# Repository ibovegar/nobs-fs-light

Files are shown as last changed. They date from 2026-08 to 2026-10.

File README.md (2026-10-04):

# Nobs FS Light

A build-it-yourself control panel for flight simulators: **6 rotary encoders** and **2 toggle
switches**, wired to an **Arduino Nano ESP32**. It plugs in over USB and shows up as a standard
game controller (HID gamepad) named **"Nobs FS Light"**, recognised directly by MSFS and the Nobs
app with no drivers to install.

Same physical layout as [Nobs Panel](https://github.com/ibovegar/nobs-fs-panel) (an 8-position
front panel), but 6 of the 8 toggle-switch positions are rotary encoders instead: each has a
push button and reports CW/CCW rotation as momentary presses, for **22 buttons** total (6 × 3 for
the encoders + 2 × 2 for the three-position switches).

## Design Philosophy

**This panel pairs precise, continuous controls with tactile, no-fuss toggles**: rotary encoders
for values you dial in (headings, altitudes, frequencies, anything you'd otherwise nudge one
degree/unit at a time), plain mechanical toggles for the handful of binary states that don't need
a knob. Both are things you can operate by feel alone, no looking needed, which keeps this
VR-friendly, and because it enumerates as a plain USB game controller, there's nothing to install
and nothing that can fall out of sync with a sim update:

* **Encoders for dialing, not clicking:** turning a knob to set a value is more natural (and more
  precise, with acceleration for fast spins) than repeatedly pressing a button.
* **Physical Switches, Not Software:** the 2 toggle switches are genuine switches with a positive
  snap, so flipping one is unambiguous even without looking.
* **Driver-Free by Design:** the board presents itself as a standard HID gamepad, so MSFS and the
  Nobs app recognise it the moment it's plugged in.

> 📸 This module is a fresh design: the enclosure, mounting plate, and front panel are modeled
> ([models/](models/)), but it hasn't been physically built yet, so there are no product photos
> here. See [docs/build-instructions.md](docs/build-instructions.md).

## Docs

- **[Build instructions](docs/build-instructions.md)**: step-by-step assembly (no photos yet, see
  above).
- **[Which wire goes where](docs/arduino-esp-32-wiring.md)**: the button + pin map.
- **[Loading the firmware](firmware/arduino_eps32_nano/README.md)**: first-time flashing,
  re-flashing, and the encoder acceleration protocol, step by step.
- **[Setting the device ID & name](docs/board-identity.md)**: how the board names itself, how to
  rename it, and how to run several panels at once (each gets its own ID + name).
- **[Bill of materials](docs/bill-of-materials.md)**: parts list.

## Nobs FS Companion App

The [**Nobs FS app**](https://github.com/ibovegar/nobs-fs-app) is the companion application for
communicating with and configuring the Nobs family of panels, including this one. It automatically
detects Nobs devices by their USB identity (VID `303A`, per-product PID block), so the right
device is selected even when other game controllers are connected.

Use it to:
* **Verify wiring & test inputs:** watch every encoder and switch register live as you turn or
  flip it, handy for confirming the build before binding anything in the sim.
* **Tune encoder feel:** adjust each encoder's acceleration sensitivity from the Settings page.
* **Track multiple panels:** the Devices page lets you add extra instances of the panel, each with
  its own ID and name (see [Setting the device ID & name](#setting-the-device-id--name-in-brief)
  below), so the app and the sim can tell them apart.

See the app repository for installation and usage details: <https://github.com/ibovegar/nobs-fs-app>

## Setting the device ID & name (in brief)

The board's name and USB product ID aren't compiled in; they're stored on the board, so the same
firmware can be set up as any Nobs profile. Out of the box this is **"Nobs FS Light"** (`303A` /
`80FC`). To change it, the configuration app sends a single line over the board's serial port:

```
SET_ID:80FC:Nobs FS Light
```

The board saves the new name + ID, replies `OK:80FC:Nobs FS Light`, and reboots so it takes effect
(`GET_ID` reads back the current values). For multiple panels, give each one the next ID in the
block, e.g. `SET_ID:80FD:Nobs FS Light 2`. Full details, including the Windows name-cache refresh,
are in **[docs/board-identity.md](docs/board-identity.md)**.

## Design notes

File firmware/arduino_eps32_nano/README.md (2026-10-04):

# Nobs FS Light: Arduino Nano ESP32 Firmware

This is the program (the "firmware") that runs on an **Arduino Nano ESP32** and turns it into a
USB game controller for Microsoft Flight Simulator. Once loaded, the board shows up to your PC and
the Nobs app as **"Nobs FS Light"** with **22 buttons**: 6 rotary encoders (CW, CCW, and push each)
and 2 three-position toggle switches. Wiring is in
[`docs/arduino-esp-32-wiring.md`](../../docs/arduino-esp-32-wiring.md).

> 👍 Everything you need is in this folder. You don't edit any Arduino files. Keep
> [`build_opt.h`](./build_opt.h) next to the sketch: the IDE uses it automatically, and the build
> fails on purpose without it. Tested with the Arduino ESP32 board package `2.0.18-arduino.5`.

## One-time setup

1. Install the **Arduino IDE** (free, from arduino.cc).
2. Add the board: **Tools → Board → Boards Manager…**, search **Arduino ESP32 Boards**, click
   **Install** (big download). Then pick **Tools → Board → Arduino ESP32 Boards → Arduino Nano ESP32**.
3. In **Tools**, set **USB Mode → `Normal mode (TinyUSB)`** and **Pin Numbering → `By Arduino pin (default)`**.

> If the board install fails ("platform not installed"), close the IDE, reopen it **as
> administrator**, and try again.

## Flashing the first time

1. Open [`arduino_eps32_nano.ino`](./arduino_eps32_nano.ino) in the Arduino IDE.
2. Plug in the board with a **data** USB cable (not charge-only), straight into the PC.
3. Click **Upload** (the round arrow).

On a fresh board this just works. 🎉 When it's done, the board reconnects as **"Nobs FS Light"**
and the app picks it up automatically.

## Re-flashing (after firmware is already on it)

This is **different**, and expected. Once the firmware is running, the board reports a custom USB
ID and no longer auto-enters upload mode, so a normal Upload fails with:

```
No DFU capable USB device available — exit status 74
```

Put the board into **update mode** by hand first:

1. Press the **RESET** button **twice, quickly** (like a mouse double-click, ~0.3–0.5 s apart).
2. You're in update mode when the **green LED breathes slowly in and out and stays there**.
   A quick red→blue→green flash that stops is just a normal reset; try the double-tap again.
3. With the green breathing, click **Upload** right away.
4. When it finishes, press **RESET once** to start the firmware.

> **If upload still can't find the board:** it's almost always the **cable or USB port**. Swap to
> a known-good data cable and a different port (this is the most common cause). The double-tap
> timing is the other one; keep trying the rhythm.

## Check it works

- **Nobs app:** the panel is detected automatically; turn the encoders and flip the switches to
  watch them react.
- **Windows:** press `Win`, type **Set up USB game controllers**, open the device's **Properties**,
  and turn/press the controls to see the 22 buttons react.

## Changing the board's name / ID

The name and product ID aren't compiled in; they're stored on the board, so the same firmware can
become any Nobs profile. Out of the box it's **"Nobs FS Light"** (`303A` / `80FC`). The
configuration app changes it over the board's serial port. See
[`docs/board-identity.md`](../../docs/board-identity.md) for how that works and the full profile
list.

## Encoder acceleration sensitivity

Each encoder's rotational acceleration (how much a fast spin multiplies presses-per-detent, vs. a
slow deliberate turn staying 1:1) is host-configurable and persisted to flash. Over the same USB
CDC serial port:

```
A0100\n   # set encoder 0 (ENC1) sensitivity to 100 (0..255)
A0?\n     # query encoder 0's current sensitivity
```

The board replies `A0=100\n` either way. Encoder indices are `0`–`5` for ENC1–ENC6. See the
comment above `applyAccelCommand()` in the sketch for the full protocol, and the comment above
`DETENT_STEPS` for how the acceleration curve itself works.

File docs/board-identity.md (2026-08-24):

# How the Board Names Itself (and How to Rename It)

This page explains, in plain language, how a Nobs board tells your PC who it is, and how you can
change that without re-installing the firmware. You don't need to understand any of this to use
the panel; it's here for the curious and for anyone setting up more than one box.

## The short version

- Every Nobs box appears to your PC as a USB game controller with a **name** (like "Nobs FS Light")
  and an **ID number** (called a *Product ID*, or **PID**).
- That name and ID are **not baked into the firmware**. The board remembers them in its own
  memory, so the *same* firmware can be set up as a panel, an autopilot, an approach box, or this
  light module.
- Out of the box, this board is **"Nobs FS Light"**. You can change it later with the configuration
  app, no re-flashing needed.

## Why each box needs its own name and ID

If you own more than one Nobs box, this matters. Microsoft Flight Simulator keeps a separate set
of button bindings for each controller, but it tells controllers apart by their **ID number**.

If two boxes shared the same ID, the simulator would treat them as the same device and **mix up
their button assignments**. Giving each box its own ID (and a clear name) keeps their controls
neatly separated, so plugging in a second or third box never disturbs the first.

Here are the standard profiles. Each product owns a small **block of IDs** so you can have several
of the same type (see below):

| If the box is a… | It should be named… | ID block |
| :--- | :--- | :--- |
| Panel | Nobs Panel | `80F0`–`80F3` |
| Autopilot | Nobs Autopilot | `80F4`–`80F7` |
| Approach | Nobs Approach | `80F8`–`80FB` |
| Light | Nobs FS Light | `80FC`–`80FF` |

(They all share the same *vendor* ID, `303A`; that part never changes.)

## Running several of the same type

You can use more than one of the same module (say two of these light panels) at the same time.
The catch is they must **not** look identical to the PC, or the simulator mixes up their bindings.
So each one gets its own ID and name from its product's block:

| | Name | ID |
| :-- | :-- | :-- |
| 1st light panel | Nobs FS Light | `80FC` |
| 2nd light panel | Nobs FS Light 2 | `80FD` |
| 3rd light panel | Nobs FS Light 3 | `80FE` |

The first one keeps the plain name and the block's first ID (its out-of-box default). For each
extra one, give it the next ID and a numbered name with the rename step below, e.g. send
`SET_ID:80FD:Nobs FS Light 2` to the second one. In the Nobs app, open **Devices** and press **+**
on that product to start tracking the extra module. The simulator then sees "Nobs FS Light" and
"Nobs FS Light 2" as two separate controllers with independent bindings.

## How to rename a board

The configuration app does this for you. Behind the scenes it just sends the board one short line
of text over its connection, for example:

```
SET_ID:80FC:Nobs FS Light
```

That reads as: *"Set your ID to `80FC` and your name to `Nobs FS Light`."* The board then:

1. **Saves** the new name and ID into its own memory.
2. **Confirms** it received them.
3. **Restarts itself** and comes back wearing the new name.

That restart is normal and only takes a second. The reason it's needed: a board can only announce
its identity to the PC at the moment it powers on, so it has to reboot for a new name to take
effect.

> 💡 To check what a board is currently called, the app can ask it with `GET_ID`, and the board
> replies with its stored name and ID.

## If Windows still shows the old name

Windows likes to remember names, so occasionally after a rename it'll keep showing the **old** one
in its game-controller list or in the simulator. If that happens, nudge it to take a fresh look:

1. Leave the board plugged in.
2. Right-click the **Start** button → open **Device Manager**.
3. Open the **Human Interface Devices** group.
4. Right-click your controller → **Uninstall device**.
5. Unplug the USB cable, wait a couple of seconds, and plug it back in.

Windows will then read the board's name again from scratch and show the updated one.

## Related pages

- [Which wire goes where](./arduino-esp-32-wiring.md): the button and pin map.
- [Loading the firmware](../firmware/arduino_eps32_nano/README.md): step-by-step setup, including
  the more technical details of how the identity is stored, and the encoder acceleration protocol.

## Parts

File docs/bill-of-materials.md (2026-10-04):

# Bill of Materials (Shopping List)

This is the full shopping list for building one Nobs FS Light: every part you need, from the
electronics to the screws. The "Manufacturer / Part Number" column lists parts known to work,
linked to their Mouser listing, so you can search for them or find equivalents.

A few friendly notes before you start buying:

- **Exact parts aren't mandatory.** The encoders, switches, terminal blocks, and stripboard can be
  swapped for similar parts you like or already have. The part numbers here are just what's known
  to work.
- **The enclosure parts (section 2) are 3D printed**: the top/bottom shells are shared with the
  rest of the Nobs family, and the mounting plate and front plate are modeled for this module's
  6-encoder / 2-switch layout. Print them yourself from the files in the `models/` folder, or have
  a print service make them.
- Quantities are for **one** panel.

## Core Electronics & Switches

| Item # | Qty | Component Description | Manufacturer / Part Number | Purpose / Application |
| :--- | :--- | :--- | :--- | :--- |
| **1.1** | 1 | Arduino Nano ESP32 (with headers) | [Arduino / ABX00083](https://no.mouser.com/ProductDetail/Arduino/ABX00083) | Main microcontroller (ESP32-S3, USB HID, VID 0x303A / PID 0x80FC) |
| **1.2** | 6 | Rotary Encoder, 12 mm, with Momentary Push Switch, 24 detents | [Bourns / PEC11R-4215F-S0024](https://www.mouser.com/ProductDetail/Bourns/PEC11R-4215F-S0024) | ENC1–ENC6 |
| **1.3** | 2 | SPDT Toggle Switch, ON-OFF-ON (3-position) | *Part number to be chosen* | SW1–SW2 |
| **1.4** | 1 | Stripboard, 50 × 80 mm | [BusBoard Prototype Systems / ST1](https://no.mouser.com/ProductDetail/BusBoard-Prototype-Systems/ST1) | Controller board carrier for the Arduino, pin headers, and terminal blocks |
| **1.5** | 2 | Female Pin Header Socket, 26-position, 2.54 mm pitch | [3M Electronic Solutions Division / 929850-01-26-RA](https://no.mouser.com/ProductDetail/3M-Electronic-Solutions-Division/929850-01-26-RA) | Sockets soldered to the stripboard to seat the Arduino Nano ESP32 |
| **1.6** | 4 | Fixed Terminal Block, 6-position, 2.54 mm pitch | [GCT / TBC05-06-1-G-G](https://no.mouser.com/ProductDetail/GCT/TBC05-06-1-G-G) | Screw-down wiring for the 22 encoder/switch signal wires and ground |
| **1.7** | 1 | 3 mm Green LED, Diffused, 2.2 V | [Lumex / SSL-LX30FT4GD](https://no.mouser.com/ProductDetail/Lumex/SSL-LX30FT4GD?qs=7jmq9uQgtYG4HR2h%252BlgbMw%3D%3D) | Front-plate status indicator |
| **1.8** | 1 | 120 Ω Resistor, 1/4 W, ±1%, Metal Film | [KOA Speer / MFS1/4DCT52R1200F](https://no.mouser.com/ProductDetail/KOA-Speer/MFS1-4DCT52R1200F?qs=ddCg%252BR5cWn20oJHZLuYO%2FQ%3D%3D) | Current-limiting resistor for the status LED |
| **1.9** | 6 | Knurled Encoder Knob, 6 mm D-shaft | Generic aftermarket | Grip/cap for ENC1–ENC6 |
| **1.10** | 2 | Toggle Switch Cap, Bat Lever, White | [NKK Switches / AT434B](https://no.mouser.com/ProductDetail/NKK-Switches/AT434B?qs=O05gvr8fLT2J5h7R71L7Aw%3D%3D) | Color-coded cap for toggle switches |

## Structural & Enclosure Hardware

| Item # | Qty | Component Description | Manufacturer / Part Number | Purpose / Application |
| :--- | :--- | :--- | :--- | :--- |
| **2.1** | 1 | Enclosure Top | 3D Printed (`models/enclosure_top.stl`) | Main upper housing shell |
| **2.2** | 1 | Enclosure Bottom | 3D Printed (`models/enclosure_bottom.stl`) | Main lower housing base, carries the controller board |
| **2.3** | 1 | Mounting Plate | 3D Printed (`models/nobs_light_mounting_plate.stl`) | Carries the 6 encoders and 2 toggle switches |
| **2.4** | 1 | Front Plate | 3D Printed (`models/nobs_light_frontpanel.stl`) | Visual faceplate with control labels |
| **2.5** | 10 | M4 Heat-Set Insert | [SI (PennEngineering) / IUTB-M4](https://no.mouser.com/ProductDetail/SI/IUTB-M4) | Threaded anchors moulded into the enclosure top/bottom |
| **2.6** | 11 | M3 Heat-Set Insert | [SI (PennEngineering) / IUTB-M3](https://no.mouser.com/ProductDetail/SI/IUTB-M3) | Threaded anchors moulded into the mounting plate and front plate |
| **2.7** | 4 | M4 × 0.7, 30 mm Socket-Head Screw | — | Clamps the enclosure top and bottom halves together |
| **2.8** | 6 | M4 × 0.7, 10 mm Socket-Head Screw | — | Fastens the mounting plate to the rear of the enclosure bottom |
| **2.9** | 4 | M3 × 0.5, 8 mm Pan-Head Screw | — | Fastens the controller board to its standoffs in the enclosure bottom |
| **2.10** | 7 | M3 × 0.5, 8 mm Countersunk Screw | — | Fastens the front plate to the mounting plate, and the assembly to the enclosure |

> ⚠️ Section 2 quantities are carried over from the other Nobs modules as a starting estimate; treat
> them as a first pass until a build confirms exact fastener counts for this module's parts.

## Connectors & Wiring

| Item # | Qty | Component Description | Manufacturer / Part Number | Purpose / Application |
| :--- | :--- | :--- | :--- | :--- |
| **3.1** | 1 | USB-C to USB-A Cable, 1.5 m to 2 m, data-sync capable | — | Connects the Arduino Nano ESP32 to your PC |
| **3.2** | 1 | Heat Shrink Tubing Assortment Pack, 1.5 mm to 3.5 mm diameters | — | Insulates soldered connections on the encoder and switch terminals |

## Tools Recommended for Assembly (Not in BOM Cost)

* **Soldering Iron & Lead-Free Rosin-Core Solder:** for attaching wires to the encoder/switch
  terminals and seating the pin headers/terminal blocks on the stripboard.
* **Wire Strippers & Flush Cutters:** for prepping the signal and ground wires.
* **Soldering Iron / Insert Tool for Heat-Set Inserts:** for pressing the brass inserts squarely
  into the 3D-printed parts.
* **Multimeter:** for testing continuity and checking for short circuits across the common ground
  loop before plugging into USB power.

## Project Costs

Rough cost estimate for a single panel, in USD. These are ballpark figures only, actual prices
vary significantly by supplier, region, and quantity, and **exclude shipping and taxes**. Several
items (heat-set inserts, screws) are sold in multi-build packs, so the per-build cost is lower if
you build more than one or already have them on hand.

| Category | Items | Estimated Cost |
| :--- | :--- | ---: |
| Microcontroller | Arduino Nano ESP32 (genuine; clones are cheaper) | $20 – $28 |
| Encoders & switches | 6 × Bourns PEC11R-4215F-S0024 + 2 × 3-position toggle switches | $30 – $50 |
| Board & connectors | Stripboard, 2 × pin headers, 4 × terminal blocks, status LED | $12 – $18 |
| Fasteners | Heat-set inserts (21) and M3/M4 screws (21) | $10 – $18 |
| Enclosure (3D printed) | Filament for top, bottom, mounting plate, front plate | $5 – $15 |
| Connectors & wiring | USB-C cable, heat-shrink tubing pack, encoder knobs | $10 – $20 |
| **Total** | | **≈ $87 – $149** |

> **Notes:**
> * The **enclosure** assumes you print the parts yourself (filament cost only). Ordering them
>   from a print service will add roughly $20 – $50.
> * This estimate doesn't include hookup wire, since it's usually bought once in bulk and reused
>   across builds.
> * Bulk/pack purchasing of the inserts, screws, and heat-shrink tubing spreads their cost across
>   multiple builds, lowering the effective per-panel total.

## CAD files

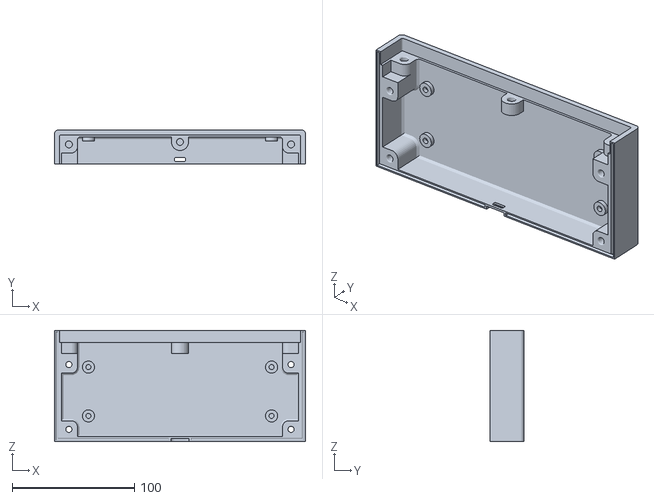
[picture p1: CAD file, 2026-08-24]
models/enclosure_top.stl
205.6 x 27.8 x 91.0

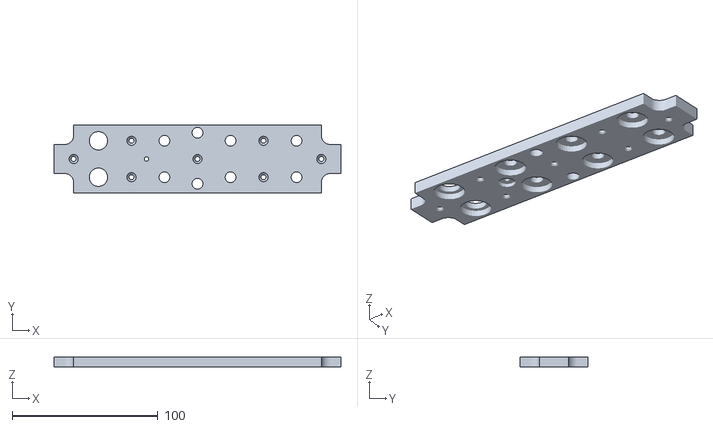
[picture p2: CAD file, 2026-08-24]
models/nobs_light_frontpanel.stl
197.0 x 47.0 x 7.00

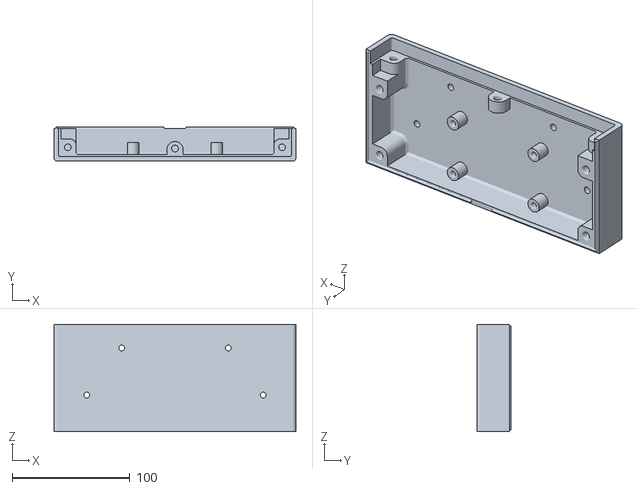
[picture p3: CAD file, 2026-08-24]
models/enclosure_bottom.stl
205.6 x 29.3 x 91.0

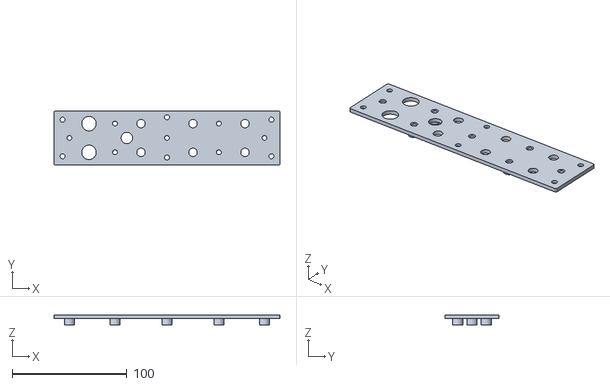
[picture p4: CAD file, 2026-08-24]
models/nobs_light_mounting_plate.stl
197.0 x 47.0 x 9.00

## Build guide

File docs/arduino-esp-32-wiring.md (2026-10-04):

# Wiring Map: Which Wire Goes Where

This table tells you which pin on the board each wire connects to, for the **Arduino Nano ESP32**.

This box has **6 rotary encoders** (ENC1–ENC6, each with an integrated push button) and **2 toggle
switches** (SW1–SW2, 3-position ON-OFF-ON). Every encoder has three signal terminals (Phase A,
Phase B, and its push-button switch terminal) plus a common terminal; every toggle switch has two
signal terminals (1 and 3) plus a common terminal (2). All the common terminals go to **GND**.

**How to read a row:** find the control (e.g. "ENC1"), look at which terminal it is ("Phase A
Terminal"), then run a wire from that terminal to the pin listed in the board's column. Pin names
like `D13` or `A0` are printed on the board itself. Every control's common terminal connects to
**GND** (ground), see the last row.

The "Virtual HID Button" column is just for reference: it's the button number the sim sees when you
turn, push, or flip that control. You don't wire anything for it.

> 💡 Each terminal has one wire to its signal pin (from this table) and the common terminal wires
> to **GND**. No resistors or extra parts needed; the firmware handles that.

| Component Group | Component Label | Hardware Connection | Arduino Nano ESP32 Pin | Virtual HID Button | Action Type |
| :--- | :--- | :--- | :--- | :--- | :--- |
| **ENC1** | Encoder 1 | Phase A Terminal | **D12** | Button 1 | CW Pulse |
| | Encoder 1 | Phase B Terminal | **D11** | Button 2 | CCW Pulse |
| | Encoder 1 | Switch Terminal | **D10** | Button 3 | Push |
| **ENC2** | Encoder 2 | Phase A Terminal | **D9** | Button 4 | CW Pulse |
| | Encoder 2 | Phase B Terminal | **D8** | Button 5 | CCW Pulse |
| | Encoder 2 | Switch Terminal | **D7** | Button 6 | Push |
| **ENC3** | Encoder 3 | Phase A Terminal | **D6** | Button 7 | CW Pulse |
| | Encoder 3 | Phase B Terminal | **D5** | Button 8 | CCW Pulse |
| | Encoder 3 | Switch Terminal | **D4** | Button 9 | Push |
| **ENC4** | Encoder 4 | Phase A Terminal | **D3** | Button 10 | CW Pulse |
| | Encoder 4 | Phase B Terminal | **D2** | Button 11 | CCW Pulse |
| | Encoder 4 | Switch Terminal | **D0** | Button 12 | Push |
| **ENC5** | Encoder 5 | Phase A Terminal | **D13** | Button 13 | CW Pulse |
| | Encoder 5 | Phase B Terminal | **D17 (A0)** | Button 14 | CCW Pulse |
| | Encoder 5 | Switch Terminal | **D18 (A1)** | Button 15 | Push |
| **ENC6** | Encoder 6 | Phase A Terminal | **D19 (A2)** | Button 16 | CW Pulse |
| | Encoder 6 | Phase B Terminal | **D20 (A3)** | Button 17 | CCW Pulse |
| | Encoder 6 | Switch Terminal | **D21 (A4)** | Button 18 | Push |
| **Switches** | Switch 1 (SW1) | Terminal 1 | **D24 (A7)** | Button 21 | Toggle (position 1) |
| | Switch 1 (SW1) | Terminal 3 | **D1** | Button 22 | Toggle (position 3) |
| | Switch 2 (SW2) | Terminal 1 | **D22 (A5)** | Button 19 | Toggle (position 1) |
| | Switch 2 (SW2) | Terminal 3 | **D23 (A6)** | Button 20 | Toggle (position 3) |
| **Ground Loop** | All Components | Common / GND Terminals (incl. SW terminal 2) | **GND** | *None* | System Ground |
| **Status LED** | Status LED | Anode, via 120 Ω resistor | **B0** | *None* | Boot/Connect Status |
| | Status LED | Cathode | **GND** | *None* | Boot/Connect Status |

> 💡 **Status LED:** wired with a 120 Ω current-limiting resistor from **B0** to **GND**. It blinks
> while the board is booting/waiting for USB enumeration and lights steady once the host PC has
> enumerated it. If no host shows up within 10 seconds it goes dark. B0 also drives the red
> channel of the board's own RGB LED (inverted), so that one glows red whenever the status LED is
> off. Leave **B1** (next to it) unconnected: it selects the chip's boot mode, and pulling it to
> ground stops the board from starting.

> 💡 **Three-position switches:** SW1 and SW2 are ON-OFF-ON toggles. Terminal 2 (centre) goes to
> **GND**; flipping to one side connects terminal 2 to terminal 1, the other side to terminal 3,
> and the centre position connects neither (both buttons released).

> 💡 **D17–D24 are the same pins as A0–A7.** Both labels are printed on the board.

> 💡 **D0/D1 as plain GPIO:** these pins double as the hardware UART (Serial) on most Arduino
> boards, but this firmware disables "USB CDC On Boot" (see
> [`firmware/arduino_eps32_nano/build_opt.h`](../firmware/arduino_eps32_nano/build_opt.h)) and never
> calls `Serial.begin()`, so they're free for plain digital input.

> 💡 **D13 is the built-in LED pin.** On the Nano ESP32, D13 doubles as the built-in amber LED
> (`LED_BUILTIN` / GPIO48), so that LED stays lit while the firmware runs. Every `D` and `A` pin on
> the board is used, which is why the status LED sits on **B0**.

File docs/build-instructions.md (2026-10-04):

# Build Instructions

> 📸 This module hasn't been physically built yet, so unlike the other Nobs repos this guide has
> no step photos. The sequence below follows the same two-stage process (controller board, then
> enclosure) as [Nobs Panel](https://github.com/ibovegar/nobs-fs-panel/blob/main/docs/build-instructions.md)
> and [Nobs Autopilot](https://github.com/ibovegar/nobs-fs-autopilot/blob/main/docs/build-instructions.md).
> Photos will be added here once a first unit is assembled.

Before starting, gather everything on the [bill of materials](bill-of-materials.md) and have the
[wiring map](arduino-esp-32-wiring.md) open for reference.

## 1. Controller board

1. Solder the two 26-position female pin header sockets to the stripboard, spaced to match the
   Arduino Nano ESP32's own header pitch, then seat the Arduino into them.
2. Solder the 4 six-position terminal blocks to the stripboard, giving you screw terminals for the
   22 signal wires (6 encoders × 3 terminals + 2 switches × 2 terminals) plus a shared ground rail.
3. Wire the 120 Ω resistor in series with the status LED's anode, and run the LED's anode/cathode
   to **B0** / **GND** as described in the wiring map. Leave **B1** (next to it) unconnected: tying
   it to ground stops the board from starting.
4. Double-check every connection against [arduino-esp-32-wiring.md](arduino-esp-32-wiring.md)
   before applying USB power. A multimeter continuity check across the ground loop catches most
   wiring mistakes early.

## 2. Encoders and switches

1. Print the mounting plate ([`models/nobs_light_mounting_plate.stl`](../models/nobs_light_mounting_plate.stl))
   and mount the 6 rotary encoders and 2 toggle switches to it.
2. Each encoder has 5 terminals: Phase A, Phase B, the push-switch's two terminals (bridge them or
   wire one to signal and the other to the shared ground rail, per the encoder's datasheet), and
   the encoder body/shaft ground tab if present. Wire Phase A, Phase B, and the push switch's
   signal terminal to their pins per the wiring map; wire every remaining common terminal to GND.
3. Each toggle switch is a 3-position ON-OFF-ON type with 3 terminals: wire terminals 1 and 3 to
   their signal pins and the centre terminal (2) to GND.
4. Insulate each soldered joint with heat-shrink tubing.
5. Press the knurled knob caps onto the encoder shafts and the bat-lever caps onto the toggle
   switches.

## 3. Firmware

Flash the sketch in [`firmware/arduino_eps32_nano/`](../firmware/arduino_eps32_nano/) following
that folder's [README](../firmware/arduino_eps32_nano/README.md). Do this before final enclosure
assembly so you can test every control (encoder rotation, encoder push, both switches) while
everything is still accessible.

## 4. Enclosure

1. Press the M4 and M3 heat-set inserts into the enclosure top/bottom, mounting plate, and front
   plate with a soldering iron or dedicated insert tool.
2. Fasten the controller board to its standoffs in the enclosure bottom with the M3 pan-head
   screws.
3. Fasten the mounting plate (with encoders and switches already installed) to the rear of the
   enclosure bottom with the M4 × 10 mm screws.
4. Fasten the front plate to the mounting plate assembly with the M3 countersunk screws.
5. Route the USB-C cable out through the enclosure's cutout, then close the top and bottom halves
   with the M4 × 30 mm screws.

## 5. Check it works

Follow [Check it works](../firmware/arduino_eps32_nano/README.md#check-it-works) in the firmware
README: confirm all 6 encoders register CW/CCW/push and both switches register on/off, either in
the Nobs app or Windows' **Set up USB game controllers** panel.

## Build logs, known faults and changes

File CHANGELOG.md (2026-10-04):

# Changelog

All notable changes to the Nobs FS Light project (hardware, firmware, and documentation) are documented in this file.

The format is based on [Keep a Changelog](https://keepachangelog.com/en/1.1.0/),
and this project adheres to [Semantic Versioning](https://semver.org/spec/v2.0.0.html).

## [Unreleased]

### Added
- Project scaffold, modeled on [nobs-fs-panel](https://github.com/ibovegar/nobs-fs-panel): same
  folder layout, `.gitignore`, and AGPLv3 license.
- Wiring map ([docs/arduino-esp-32-wiring.md](docs/arduino-esp-32-wiring.md)): 6 encoders (18
  pins) + 2 three-position toggle switches (4 pins) fill every D/A pin on the Arduino Nano ESP32,
  with the status LED on B0.
- Bill of Materials ([docs/bill-of-materials.md](docs/bill-of-materials.md)): core electronics,
  encoders, switches, structural/enclosure hardware (pending final mounting-plate design), and a
  per-panel project cost estimate.
- Build instructions ([docs/build-instructions.md](docs/build-instructions.md)): textual walkthrough
  covering controller board, encoders/switches, firmware, and enclosure; no step photos yet since
  the module hasn't been physically built.
- Board identity guide ([docs/board-identity.md](docs/board-identity.md)), reserving PID block
  `80FC`–`80FF` / "Nobs FS Light" in the shared Nobs USB ID scheme (after Panel `80F0`–`80F3`,
  Autopilot `80F4`–`80F7`, Approach `80F8`–`80FB`).
- Arduino Nano ESP32 firmware sketch
  ([firmware/arduino_eps32_nano/arduino_eps32_nano.ino](firmware/arduino_eps32_nano/arduino_eps32_nano.ino)):
  6-encoder quadrature decoding, per-encoder acceleration, and dynamic USB identity, adapted from
  [nobs-fs-autopilot](https://github.com/ibovegar/nobs-fs-autopilot)'s proven encoder code, plus 2
  three-position (ON-OFF-ON) toggle switches read through both outer terminals, for 22 HID
  buttons. Before starting its own USB the firmware briefly drops the USB pull-up, so the host
  sees the chip's boot-time `303A:1001` device disconnect and enumerates the Nobs device on a
  cold plug-in (without it the board was only detected right after a flash).
- Enclosure, mounting plate, and front panel CAD
  ([models/](models/): shared `enclosure_top`/`enclosure_bottom` shells plus new
  `nobs_light_mounting_plate.stl` and `nobs_light_frontpanel.stl` for the 6-encoder / 2-switch
  layout).
- `images/` placeholder, pending a first physical build.

[Unreleased]: https://github.com/ibovegar/nobs-fs-light/commits/main

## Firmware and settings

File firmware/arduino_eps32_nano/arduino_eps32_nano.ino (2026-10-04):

// Nobs FS Light — Arduino Nano ESP32 (ESP32-S3) USB HID gamepad firmware.
//
// A lighter sibling of the Nobs Autopilot build: same encoder-decoding approach,
// scaled to 6 encoders, with 2 three-position (ON-OFF-ON) toggle switches standing in
// for the other two boxes' larger switch banks. Exposes 22 buttons in the exact order
// the nobs-fs app expects:
//   buttons  0..17  → 6 encoders × (CW, CCW, push)
//   buttons 18..21  → 2 toggle switches × 2 (SW2 pos1, SW2 pos3, SW1 pos1, SW1 pos3)
// See docs/arduino-esp-32-wiring.md for the full button + pin table.
//
// Host config: over the USB CDC serial port the app sets encoder acceleration
// sensitivity and can reassign the board's USB identity — see the serial protocol
// near handleSerialConfig().
//
// ── Arduino IDE Tools settings (required) ─────────────────────────────────────
//   Board:        "Arduino Nano ESP32"
//   USB Mode:     "Normal mode (TinyUSB)"    ← the default; needed for custom HID
//   Pin Numbers:  "By Arduino pin (default)"  so D0/A0… match the wiring doc
// No other Tools changes and NO edits to the installed Arduino core are needed — the
// whole USB-identity fix lives in this repo (this sketch + build_opt.h beside it).
//
// ── USB identity: dynamic, stored in NVS (Preferences) ────────────────────────
// The device enumerates with VID 0x303A (Espressif's vendor ID) and a PID + product
// name that are *configurable at runtime*. Each Nobs box gets its own PID so MSFS
// can't mirror/overwrite control bindings across panels. Out of the box this build
// defaults to PID 0x80FC / "Nobs FS Light" (matches the `light` entry in the app's
// device registry, src/panel/panel.ts).
//
// The PID and name live in flash via the native Preferences library (NVS). On boot
// the firmware reads them *before* USB.begin() and applies them to the descriptor.
// The configuration app can change them over the USB CDC serial port (see the serial
// protocol below); after a change the firmware reboots so USB re-enumerates.
//
// That only works because the Nano ESP32 normally forces "USB CDC On Boot" and "DFU On
// Boot" on, which would make the core bring USB up at boot (before setup()), freezing
// the descriptor with the stock 0x2341/0x0070 identity. The build_opt.h file next to
// this sketch overrides both to 0 (it is appended to every compile, including the
// core's), so the boot-time USB.begin() is skipped and our runtime identity wins.
//
// Because "CDC On Boot" is then off, the core's `Serial` is the hardware UART — so the
// app's config port is our own USB CDC interface (the USBSerial object below). That
// also frees D0/D1 (normally UART0 TX/RX) for plain digital input, which is how SW1
// gets one of its pins below.
//
// Re-flashing: the running firmware reports a custom PID (and, with DFU-on-boot off, no
// DFU runtime interface), so the IDE can't auto-enter the bootloader. Double-tap the
// RESET button (RGB LED pulses) before uploading. See this folder's README.md.

#include "USB.h"
#include "USBHID.h"
#include "USBCDC.h"
#include <EEPROM.h>
#include <Preferences.h>
#include "soc/usb_serial_jtag_reg.h"

#if ARDUINO_USB_MODE
#error "Set Tools > USB Mode to 'Normal mode (TinyUSB)'. Custom HID needs the TinyUSB stack."
#endif
#if ARDUINO_USB_CDC_ON_BOOT
#error "build_opt.h is not taking effect: ARDUINO_USB_CDC_ON_BOOT must be 0. Make sure build_opt.h sits next to this .ino (it disables CDC/DFU-on-boot so the runtime USB identity works)."
#endif

// ── Custom HID gamepad: 22 buttons, no axes ───────────────────────────────────
// 22 1-bit buttons + 2 bits of padding = a flat 3-byte report, driven through the
// ESP32 core's USBHID device interface (same descriptor shape as Nobs Autopilot).
static const uint8_t HID_REPORT_DESCRIPTOR[] = {
  0x05, 0x01,        // Usage Page (Generic Desktop)
  0x09, 0x05,        // Usage (Game Pad)
  0xA1, 0x01,        // Collection (Application)
  0x05, 0x09,        //   Usage Page (Button)
  0x19, 0x01,        //   Usage Minimum (Button 1)
  0x29, 0x16,        //   Usage Maximum (Button 22)
  0x15, 0x00,        //   Logical Minimum (0)
  0x25, 0x01,        //   Logical Maximum (1)
  0x75, 0x01,        //   Report Size (1)
  0x95, 0x16,        //   Report Count (22)
  0x81, 0x02,        //   Input (Data,Var,Abs)
  0x75, 0x01,        //   Report Size (1)
  0x95, 0x02,        //   Report Count (2)   — padding to a whole byte
  0x81, 0x03,        //   Input (Const,Var,Abs)
  0xC0               // End Collection
};

class NobsGamepad : public USBHIDDevice {
public:
  NobsGamepad() { HID.addDevice(this, sizeof(HID_REPORT_DESCRIPTOR)); }

  void begin() { HID.begin(); }

  // Set/clear one button bit in the pending report (mirrors Joystick.setButton).
  void setButton(uint8_t index, uint8_t value) {
    if (index >= 22) return;
    uint8_t byteIdx = index >> 3;
    uint8_t mask    = 1 << (index & 7);
    if (value) report[byteIdx] |= mask;
    else       report[byteIdx] &= ~mask;
  }

  // One USB report carrying every button change since the last call (mirrors
  // Joystick.sendState). Only transmitted when something actually changed — HID
  // hosts track button state edge-to-edge, so re-sending identical reports just
  // adds USB traffic and risks blocking the loop.
  void sendState() {
    if (memcmp(report, lastSent, sizeof(report)) == 0) return;
    if (HID.SendReport(0, report, sizeof(report))) {
      memcpy(lastSent, report, sizeof(report));
    }
  }

  // USBHIDDevice: hand the descriptor to the core during enumeration.
  uint16_t _onGetDescriptor(uint8_t* buffer) override {
    memcpy(buffer, HID_REPORT_DESCRIPTOR, sizeof(HID_REPORT_DESCRIPTOR));
    return sizeof(HID_REPORT_DESCRIPTOR);
  }

private:
  USBHID  HID;
  uint8_t report[3]   = { 0, 0, 0 };
  uint8_t lastSent[3] = { 0xFF, 0xFF, 0xFF }; // force the first real report out
};

NobsGamepad Joystick;

// USB CDC config port. With CDC-on-boot disabled (via build_opt.h) the core's `Serial`
// is the hardware UART, so we expose our own USB CDC interface for the app's Settings
// page. Like USBHID, USBCDC registers its interface in its constructor (static init),
// so it is in place before USB.begin() builds the composite descriptor in setup().
USBCDC USBSerial;

// ── Dynamic USB identity (NVS via Preferences) ────────────────────────────────
// VID is fixed (Espressif's vendor ID); PID + product name are stored in flash and
// host-configurable. Defaults are the light profile; an unconfigured chip uses them.
// (Acceleration uses the emulated-EEPROM store below; identity uses its own
// Preferences namespace, so the two don't collide.)
// NB: named NOBS_USB_VID, not USB_VID — the core's pins_arduino.h #defines USB_VID.
const uint16_t NOBS_USB_VID  = 0x303A;
const uint16_t DEFAULT_PID   = 0x80FC;
const char*    DEFAULT_NAME  = "Nobs FS Light";
const char*    NVS_NAMESPACE = "nobs";
const char*    NVS_KEY_PID   = "pid";
const char*    NVS_KEY_NAME  = "name";

Preferences prefs;
uint16_t     usbPid;  // active PID (kept alive for the whole session)
String       usbName; // active product name (c_str() must outlive USB.begin())

void loadIdentity() {
  prefs.begin(NVS_NAMESPACE, true); // read-only
  usbPid  = prefs.getUShort(NVS_KEY_PID, DEFAULT_PID);
  usbName = prefs.getString(NVS_KEY_NAME, DEFAULT_NAME);
  prefs.end();
}

void storeIdentity(uint16_t pid, const String& name) {
  prefs.begin(NVS_NAMESPACE, false); // read-write
  prefs.putUShort(NVS_KEY_PID, pid);
  prefs.putString(NVS_KEY_NAME, name);
  prefs.end();
}

// ── USB string descriptors: name the interfaces after the product ─────────────
// The core hardcodes the HID/CDC *interface* strings to "TinyUSB HID"/"TinyUSB CDC".
// For a composite device (HID + CDC) Windows and MSFS show that interface string as
// the controller's name — so without this it shows up as "TinyUSB HID" even though
// iProduct is "Nobs FS Light". tud_descriptor_string_cb is weak in the core, so
// defining it here replaces it (no core edit needed) and points every interface
// string at the product name. Index map: 0=language, 1=manufacturer, 2=product,
// 3=serial (from the chip MAC, stable per board), 4+=interface strings → product.
extern "C" const uint16_t* tud_descriptor_string_cb(uint8_t index, uint16_t langid) {
  (void)langid;
  static uint16_t desc[40];

  if (index == 0) {
    desc[1] = 0x0409; // English (United States)
    desc[0] = (uint16_t)((3 << 8) | (2 * 1 + 2));
    return desc;
  }
  // Beyond our real strings (1..3 + a handful of interface strings). Returning NULL
  // mirrors the core and lets Windows' MS-OS probe at index 0xEE fail cleanly.
  if (index >= 16) return NULL;

  char serial[16];
  const char* str;
  switch (index) {
    case 1: str = "Arduino"; break;       // manufacturer (matches USB.manufacturerName)
    case 2: str = usbName.c_str(); break; // product (iProduct)
    case 3:                               // serial — stable per board
      snprintf(serial, sizeof(serial), "%012llX", (unsigned long long)ESP.getEfuseMac());
      str = serial;
      break;
    default: str = usbName.c_str(); break; // HID/CDC/config interface strings
  }

  uint8_t chr_count = strlen(str);
  if (chr_count > 38) chr_count = 38; // desc holds 39 UTF-16 chars + the header word
  for (uint8_t i = 0; i < chr_count; i++) desc[1 + i] = str[i];
  desc[0] = (uint16_t)((3 << 8) | (2 * chr_count + 2));
  return desc;
}

// ── Pin assignments (Arduino Nano ESP32 labels — see arduino-esp-32-wiring.md) ─
// Encoders: A/B quadrature pins + S push button. Encoder common terminals and the
// switches' common terminals are all wired to GND.
//
// Every D/A header pin is used (the status LED sits on B0, see below). A0..A7 are the
// same pins as D17..D24. D13 doubles as
// the built-in amber LED (GPIO48), so that LED stays lit while the firmware runs.
const uint8_t encA[6]    = { D12, D9, D6, D3, D13, A2 };
const uint8_t encB[6]    = { D11, D8, D5, D2, A0,  A3 };
const uint8_t encPush[6] = { D10, D7, D4, D0, A1,  A4 };

// 3-position ON-OFF-ON toggle switches SW1..SW2: terminals 1 and 3 go to the MCU and
// the common (2) to GND. Centre = neither pin LOW. Order: SW2 t1, SW2 t3, SW1 t1, SW1 t3.
const uint8_t swPin[4]   = { A5, A6, A7, D1 };

// NOTE: every pin above is driven with INPUT_PULLUP, so the closed-to-GND wiring
// reads LOW = pressed. All of these GPIOs support the ESP32-S3 internal pull-up;
// if a future revision moves a signal onto a pull-up-less pad, add an external
// 10 kΩ pull-up to 3V3 there.

// ── Status LED (B0) ────────────────────────────────────────────────────────────
// Blinks while booting/waiting for USB enumeration, steady once enumerated. All the
// D/A pins are taken by the controls, so the LED sits on the B0 header pin. B0 is
// GPIO46, which the core names LED_RED: it also drives the red channel of the
// on-board RGB LED, active-low, so that one shows the inverse of the status LED.
// GPIO46 is a boot strapping pin that must read LOW at reset; the LED + resistor to
// GND keeps it there. (Never use B1 instead: that is GPIO0, the boot-mode pin.)
const uint8_t STATUS_LED_PIN = LED_RED;

// ── Button index map (must match the wiring doc / src/panel/panel.ts) ─────────
const uint8_t encBase[6] = { 0, 3, 6, 9, 12, 15 }; // CW = base, CCW = base + 1, push = base + 2
const uint8_t swBase     = 18;

// ── Encoder rotation state ────────────────────────────────────────────────────
// Full quadrature decode: every loop read both A and B and accumulate only valid
// Gray-code transitions. Sampling B at a single A edge mis-read direction (CCW
// triggered false CW); here a bounce that jumps two bits, or wiggles back and
// forth, nets to zero — no false steps in either direction, and it doesn't care
// where the detent rests. One detent = one full cycle = 4 counts, so we emit a
// CW/CCW step each time the accumulator crosses ±DETENT_STEPS.
//
// Each detent becomes one or more momentary CW/CCW presses, *queued* rather than
// held: a held-and-re-armed button (the old approach) merged into one long press
// when you spun fast, so rapid rotation lost counts. The generator emits each
// queued press as a pulse (PULSE_ON_MS) + forced low gap (PULSE_GAP_MS) so each
// one is counted as a distinct press.
//
// Pulse length is sized for MSFS, NOT the web app. The app reads every ~1 ms USB
// report, so it counts even 2 ms pulses — but MSFS only samples gamepad state
// about once per frame (~16–33 ms). A pulse shorter than a frame can begin and end
// between two MSFS samples and never register, which is why fast spins moved the
// heading bug barely or not at all. To make MSFS see each press we hold it (and the
// gap after it) for about one frame at 60 fps (~16 ms), capping the emit rate at
// ~1000/(ON+GAP) ≈ 33 presses/s — the practical ceiling, since MSFS counts each
// press as 1° so max heading-bug rate ≈ that many °/s. If the sim runs below 60 fps
// (or stutters), a press can again fall between samples; bump ON/GAP back toward 20
// ms if steps go missing. The queue clamp is small so a fast flick's tail drains in
// ~0.25 s, not seconds.
const int8_t        DETENT_STEPS   = 4;  // quadrature counts per detent
const unsigned long PULSE_ON_MS    = 15; // CW/CCW button held high per press (~1 MSFS frame @ 60 fps)
const unsigned long PULSE_GAP_MS   = 15; // forced low gap between presses (~1 MSFS frame @ 60 fps)
const int8_t        STEP_QUEUE_MAX = 8;  // clamp pending steps (bounds post-spin tail to ~0.25 s)

// Rotational acceleration: presses emitted per detent grow with spin speed (the
// time since the previous detent on that encoder). A slow, deliberate turn stays
// 1:1 for single-unit precision; a fast flick multiplies, so e.g. the MSFS heading
// bug races instead of crawling 1° per detent. Tune the thresholds/multipliers to
// taste. Kept within the emit ceiling so the queue (and its tail) stays small.
const unsigned long ACCEL_T1 = 80; // ms between detents; slower than this → ×1
const unsigned long ACCEL_T2 = 40; // ms
const unsigned long ACCEL_T3 = 20; // ms; faster than this → fastest multiplier
const int8_t        ACCEL_M1 = 2;  // ACCEL_T2..ACCEL_T1 ms apart
const int8_t        ACCEL_M2 = 5;  // ACCEL_T3..ACCEL_T2 ms apart
const int8_t        ACCEL_M3 = 10; // faster than ACCEL_T3 (fast flick)

// Acceleration sensitivity (0..255), *per encoder*, host-configurable and saved in
// emulated EEPROM (flash). It scales the *extra* presses from the curve above: 0 =
// acceleration off (always 1:1), 255 = the full ACCEL_M* multipliers. Each encoder
// i uses EEPROM byte EEPROM_ADDR_ACCEL + i; an uninitialised byte reads 0xFF (=255),
// so the out-of-box default is full acceleration on every knob.
const int     EEPROM_SIZE       = 8;
const int     EEPROM_ADDR_ACCEL = 0;
uint8_t       accelSens[6] = { 255, 255, 255, 255, 255, 255 };

// ESP32's EEPROM is emulated in flash: writes are buffered until commit(). Mirror
// the AVR EEPROM.update() — only touch flash when the value actually changes.
void eepromUpdate(int addr, uint8_t value) {
  if (EEPROM.read(addr) != value) {
    EEPROM.write(addr, value);
    EEPROM.commit();
  }
}

// Direction of each (prevAB << 2 | currAB) transition: +1 CW, -1 CCW, 0 none/invalid.
// Derived from the confirmed orientation: A-falling-with-B-high (11→01) is CW.
const int8_t qdec[16] = {
   0, -1,  1,  0,
   1,  0,  0, -1,
  -1,  0,  0,  1,
   0,  1, -1,  0,
};

uint8_t       prevAB[6];     // last (A<<1 | B) phase per encoder
int8_t        accum[6];      // accumulated quadrature counts toward a detent
int8_t        pending[6];    // queued steps not yet pulsed (signed: + CW, − CCW)
unsigned long lastStepMs[6]; // millis() of the previous detent (for acceleration)
bool          pulseOn[6];    // is a CW/CCW press currently asserted?
int           pulseBtn[6];   // which button that press is on
unsigned long phaseUntil[6]; // millis() when the current on/gap phase ends

// ── Host serial config ───────────────────────────────────────────────────────
// Line protocol over the USB CDC port (the app's Settings page).
//
// Acceleration — each encoder has its own sensitivity, addressed by a single-digit
// index i (0..5):
//   "A<i><n>\n"  set encoder i sensitivity to n (0..255), persisted to EEPROM
//   "A<i>?\n"    query encoder i sensitivity
// Either way we reply "A<i>=<n>\n" so the host can confirm/read the stored value.
//
// Identity — reassign the board's USB PID + product name (persisted to NVS):
//   "SET_ID:<pidHex>:<name>\n"  store PID (hex, e.g. 80FC) + name, then soft-reboot
//                               so the new identity takes effect; replies "OK:<pid>:<name>"
//   "GET_ID\n"                  reply "ID:<pidHex>:<name>" with the stored values
char    cmdBuf[64];
uint8_t cmdLen = 0;

void applyAccelCommand(const char* s) {
  if (s[0] != 'A') return;
  uint8_t i = s[1] - '0';
  if (i >= 6) return;          // need a valid encoder index (0..5)
  const char* rest = s + 2;    // value or '?' follows the index
  if (rest[0] != '?' && rest[0] != '\0') {
    long v = atol(rest);
    if (v < 0) v = 0;
    else if (v > 255) v = 255;
    accelSens[i] = (uint8_t)v;
    eepromUpdate(EEPROM_ADDR_ACCEL + i, accelSens[i]); // only writes if changed
  }
  USBSerial.print('A');
  USBSerial.print(i);
  USBSerial.print('=');
  USBSerial.println(accelSens[i]);
}

void printIdentity(const char* prefix) {
  char pidHex[5];
  snprintf(pidHex, sizeof(pidHex), "%04X", usbPid);
  USBSerial.print(prefix);
  USBSerial.print(':');
  USBSerial.print(pidHex);
  USBSerial.print(':');
  USBSerial.println(usbName);
}

void applyIdCommand(const char* s) {
  if (strcmp(s, "GET_ID") == 0) {
    printIdentity("ID");
    return;
  }
  if (strncmp(s, "SET_ID:", 7) != 0) return;

  const char* p     = s + 7;          // "<pidHex>:<name>"
  const char* colon = strchr(p, ':');
  if (!colon || colon == p) return;   // need a PID and a separator

  char pidStr[8] = { 0 };
  size_t n = colon - p;
  if (n >= sizeof(pidStr)) return;
  memcpy(pidStr, p, n);
  uint16_t pid = (uint16_t)strtol(pidStr, nullptr, 16);

  String name = colon + 1;            // everything after the second ':'
  name.trim();
  if (name.length() == 0) return;

  storeIdentity(pid, name);
  usbPid  = pid;                       // reflect the just-stored values
  usbName = name;
  printIdentity("OK");
  USBSerial.flush();
  delay(50);                           // let the CDC packet drain before reset
  ESP.restart();
}

void applyConfigCommand(const char* s) {
  if (strncmp(s, "SET_ID:", 7) == 0 || strcmp(s, "GET_ID") == 0) applyIdCommand(s);
  else applyAccelCommand(s);
}

void handleSerialConfig() {
  while (USBSerial.available()) {
    char c = USBSerial.read();
    if (c == '\n' || c == '\r') {
      cmdBuf[cmdLen] = '\0';
      if (cmdLen > 0) applyConfigCommand(cmdBuf);
      cmdLen = 0;
    } else if (cmdLen < sizeof(cmdBuf) - 1) {
      cmdBuf[cmdLen++] = c;
    } else {
      cmdLen = 0; // overlong line (no newline) — drop it and resync
    }
  }
}
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
void loop() {
  unsigned long now = millis();

  handleSerialConfig(); // apply any pending acceleration-sensitivity command
  updateStatusLed();    // blink while waiting for USB enumeration, steady once enumerated

  // ── Encoders ────────────────────────────────────────────────────────────────
  for (uint8_t i = 0; i < 6; i++) {
    // Accumulate valid quadrature transitions; emit a step each full detent.
    uint8_t ab = (digitalRead(encA[i]) << 1) | digitalRead(encB[i]);
    if (ab != prevAB[i]) {
      accum[i] += qdec[(prevAB[i] << 2) | ab];
      prevAB[i] = ab;

      int8_t dir = 0;
      if (accum[i] >= DETENT_STEPS) {
        dir = 1;            // clockwise  → CW
        accum[i] -= DETENT_STEPS;
      } else if (accum[i] <= -DETENT_STEPS) {
        dir = -1;           // counter-cw → CCW
        accum[i] += DETENT_STEPS;
      }

      if (dir != 0) {
        // Acceleration: scale presses-per-detent by how fast we're turning, then
        // by the host-set sensitivity (0 = off/1:1, 255 = full curve).
        unsigned long delta = now - lastStepMs[i];
        lastStepMs[i] = now;
        int8_t baseMult = (delta < ACCEL_T3) ? ACCEL_M3
                        : (delta < ACCEL_T2) ? ACCEL_M2
                        : (delta < ACCEL_T1) ? ACCEL_M1
                        : 1;
        int16_t mult = 1 + ((int16_t)(baseMult - 1) * accelSens[i]) / 255;
        // Queue the (scaled) steps, clamped; the generator below paces them out.
        int16_t want = pending[i] + (int16_t)dir * mult;
        if (want > STEP_QUEUE_MAX) want = STEP_QUEUE_MAX;
        else if (want < -STEP_QUEUE_MAX) want = -STEP_QUEUE_MAX;
        pending[i] = (int8_t)want;
      }
    }

    // Pulse generator: turn queued steps into distinct press/gap cycles so even
    // rapid rotation counts every detent.
    if (pulseOn[i]) {
      if (now >= phaseUntil[i]) {           // end the press → start the low gap
        Joystick.setButton(pulseBtn[i], 0);
        pulseOn[i] = false;
        phaseUntil[i] = now + PULSE_GAP_MS;
      }
    } else if (now >= phaseUntil[i] && pending[i] != 0) {
      int8_t dir = (pending[i] > 0) ? 1 : -1; // start the next queued press
      pending[i] -= dir;
      pulseBtn[i] = (dir > 0) ? encBase[i] : encBase[i] + 1;
      Joystick.setButton(pulseBtn[i], 1);
      pulseOn[i] = true;
      phaseUntil[i] = now + PULSE_ON_MS;
    }

    // Push button is reported as a held level (pressed = LOW with INPUT_PULLUP).
    Joystick.setButton(encBase[i] + 2, digitalRead(encPush[i]) == LOW ? 1 : 0);
  }

  // ── Toggle switches ────────────────────────────────────────────────────────
  for (uint8_t i = 0; i < 4; i++) {
    Joystick.setButton(swBase + i, digitalRead(swPin[i]) == LOW ? 1 : 0);
  }

  // One USB report per loop with all the updates above (sent only when changed).
  Joystick.sendState();
}

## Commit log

2026-08-24 Scaffold Nobs FS Light project
    Build-it-yourself panel with 6 rotary encoders + 2 toggle switches on an
    Arduino Nano ESP32, same folder structure/license/gitignore as nobs-fs-panel:
    - Firmware (arduino_eps32_nano.ino): 6-encoder quadrature decoding + per-encoder
    acceleration adapted from nobs-fs-autopilot, 2 single-pin toggle switches,
    dynamic USB identity (VID 303A / PID 80FC, "Nobs FS Light"), 20-button HID
    report.
    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
    [enclosure_bottom.stl, enclosure_top.stl, nobs_light_frontpanel.stl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]
2026-10-04 Rewire to the built pinout: 3-position switches, status LED on B0, USB hand-over fix
    - Encoders and switches follow the as-built wiring; SW1/SW2 are now
    3-position ON-OFF-ON toggles read through both outer terminals, so the
    HID report grows from 20 to 22 buttons.
    - Status LED moves from D4 to B0 (every D/A pin is taken) and goes dark
    after 10 s without a host, as on Nobs Autopilot.
    - Drop the USB D+ pull-up briefly before USB.begin() so the host sees the
    chip's boot-time 303A:1001 device disconnect and enumerates the Nobs
    device on a cold plug-in; before, the board was only detected right
    after a flash.
    - Wiring map, BOM, build instructions and READMEs updated to match.
    Co-Autho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
    [arduino_eps32_nano.ino]
2026-11-02 Add wiring diagram as SVG and HTML
    The same pins and layout as the existing wiring doc, drawn with each
    control beside the header pins it connects to. The SVG is on a white
    background; the HTML page follows the light/dark theme.
